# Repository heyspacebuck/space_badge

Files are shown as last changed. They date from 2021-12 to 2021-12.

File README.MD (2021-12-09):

# Space Buck's Space Badge

## Thoughts on designing a con badge with boopability

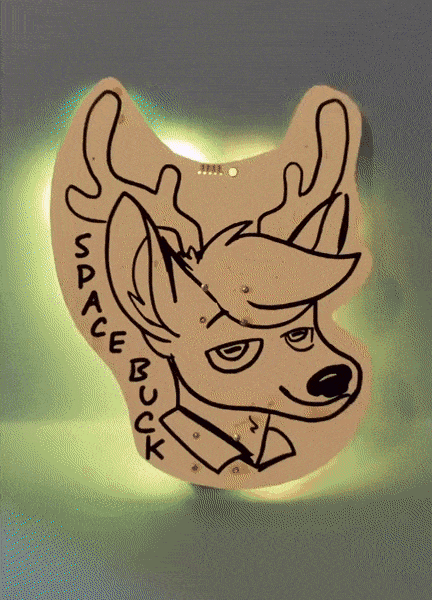
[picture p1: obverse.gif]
Animated gif of a deer face with animated backlighting


You probably don't need to be told that con badges are useful. Meeting someone in-person when you've only ever seen their avatar and username can be disorienting! This is especially true for real-life events in the furry fandom. A good fur con badge isn't just a nametag, it also shows off some facet of the wearer's personality. "Oh I know that panther, they're good at metalworking," "Oh I know that bear, she cards her own yarn," "Hey it's Space Buck, he makes goofy electronics!"

Naturally I thought it would be fun to make a PCB con badge for myself. The obverse face has, well, my face, and three large copper pours for capacitive touch purposes. The reverse has twelve WS2812B addressable LEDs, an ATtiny85, and a trio of dead-simple AT42QT1011 capacitive touch sensors. It's powered by a pair of 10440 li-ion cells and a 5V LDO, simply because I have a ton of those lying around. The ATtiny85 is programmed in-circuit with a SOICbite connector. In theory I could have just used the SOIC clip as intended, but for whatever reason I can never get them to make secure connections that way.

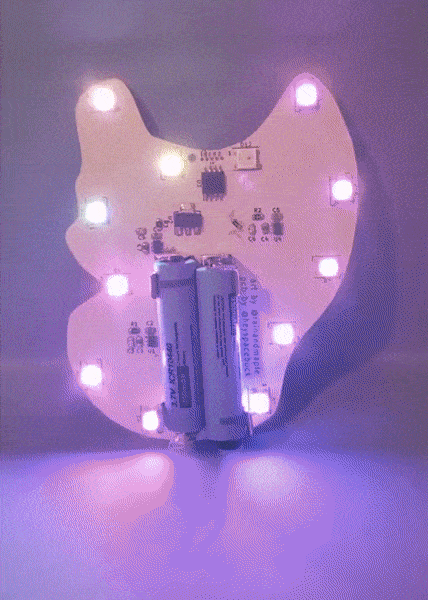
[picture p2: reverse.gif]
Animated gif of the reverse face of the PCB


How it works: The copper pours under the nose and the antlers are the only inputs and the RGB LEDs are the only outputs. Booping the snoot turns the system on or off. When on, one of six FastLED patterns plays across the LEDs. To switch to the next/previous patterns, just touch the right/left antlers.

The cute art is by [Fenn, @rainandmaple on Twitter](https://twitter.com/rainandmaple)! I got white soldermask because I intend to paint it someday. The git repo contains the circuit I used, but not Fenn's artwork. I don't recommend using the same circuit I used! Which brings us to future hardware improvements....

## Future hardware improvements

I'm happy with the badge for myself, but if I were making one for someone else, I'd put a lot more care into it. A physical power switch, for sure. A more normal Li-Po pouch battery, and a built-in USB charge circuit (sorry not sorry, I'm still using USB Micro B ports on all my designs). More LED patterns. I've designed a proof-of-concept circuit but haven't tried it for real yet.

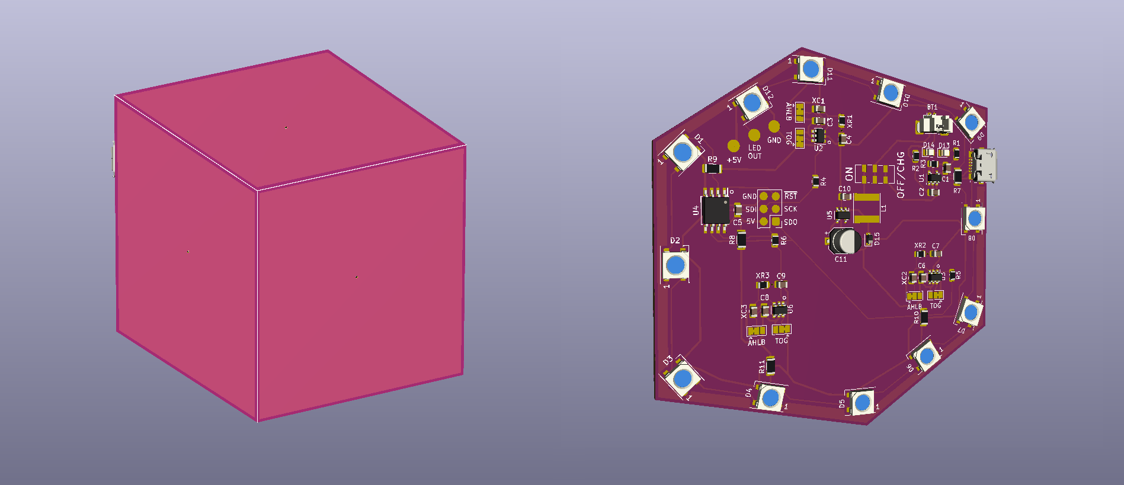
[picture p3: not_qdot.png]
KiCad render of an updated PCB badge circuit


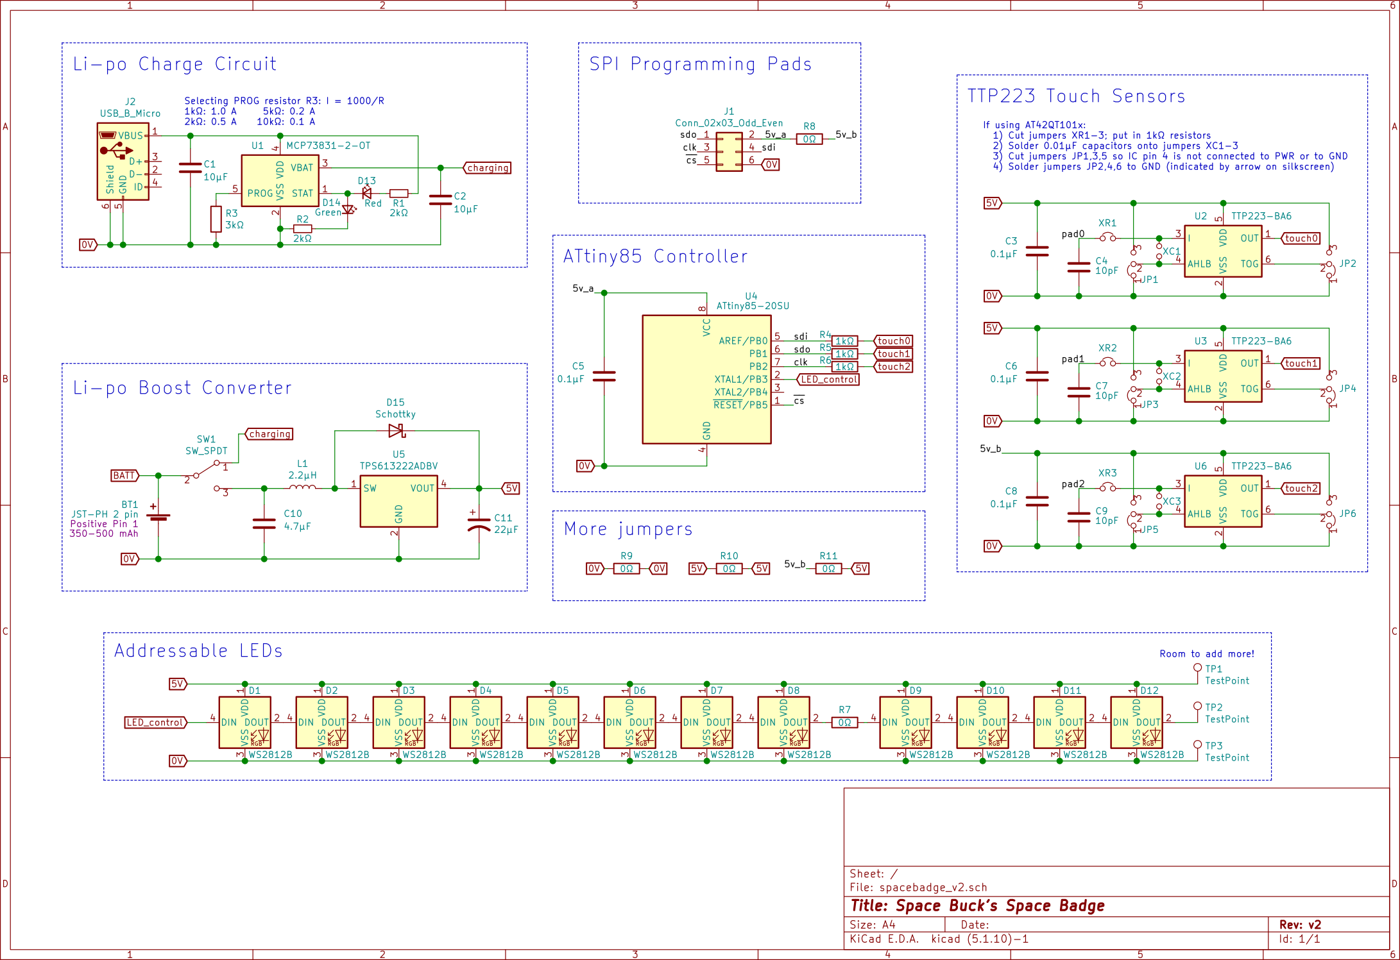
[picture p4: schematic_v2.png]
Schematic of an updated PCB badge circuit


### Power consumption

It should be easy to set up deep-sleep mode on the ATtiny85 and wait for an interrupt to turn the LEDs on. I suppose it's still possible to update this version to do that; I'd just have to update the code. In fact, I think I will do that!

...

Okay I'm back, the badge now enters deep-sleep mode when the lights are off and turns back on with a pin change interrupt. Now I know to attach this specific touch sensor to the INT0 pin (PB0, pin 5) for an easier time detecting rising-edge interrupts only.

### Power supply

The first badge's power system is bad: two 10440 li-ion cells in series, dropped to 5V with an LDO. I only did this because those were the parts I had on-hand. Were I building this for someone else, I'd use a regular pouch li-po cell, something in the 350-500 mAh range, and a boost converter like the TPS613222A to get the 5 volts expected by the WS2812b LEDs. And, of course, a built-in recharging circuit. I'd also add a physical power switch. We don't want the cap-touch sensors turning the badge on at inopportune times.

### Programming

Goodbye, SOICbite. The next version of the badge will have *no* visible copper on the obverse face. The SOICbite is lovely but as long as I'm using a SOIC-8 microcontroller I should just use the SOIC clip as intended. That said, I have trouble with keeping my SOIC clip to secured on the IC, and I like offering large pads for soldering wires to, so I've also stuck on some SMD pads that can be soldered to or probed with pogo pins.

The light show patterns are demos from the FastLED Arduino library. When compiled the current sketch uses about 70% of the ATtiny85's 8k flash, and about 40% of the RAM, so there's plenty of room for new features.

### Part flexibility

Ah, the chip shortage. Judging by the AT42QT101x lead times, I won't be using that IC in any designs for a while. The TTP223, which is a similar and much cheaper chip, is still available from many places, so I can adjust my designs to use that without much fuss. Alternately, I'd like to try turning some ATtiny10's into cap-touch sensors! The datasheet promises that Atmel's QTouch capacitive touch library is supported, but the actual documentation and libraries are nearly impossible to find on their website. Someone from Microchip guided me through the maze of broken links to get to some inscrutable libraries and an ATtiny10-specific tool that I'd describe as "so Visual Basic it hurts". It will take some time (and I'll have to find my HV programmer) but that's something to look forward to.

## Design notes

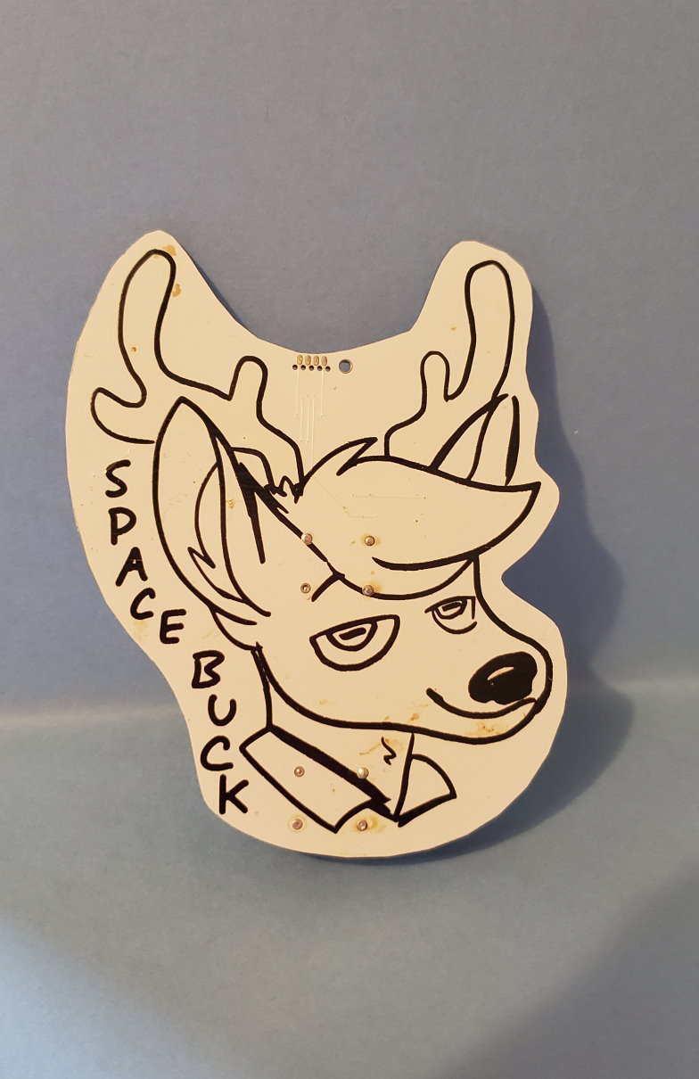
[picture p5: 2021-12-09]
obverse.jpg

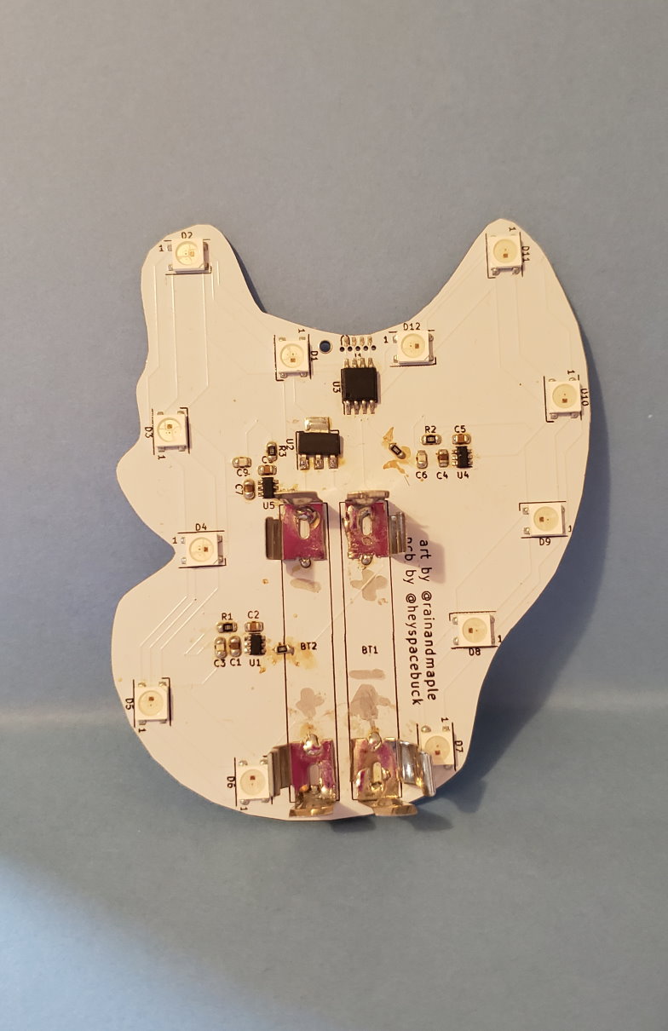
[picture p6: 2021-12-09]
reverse.jpg

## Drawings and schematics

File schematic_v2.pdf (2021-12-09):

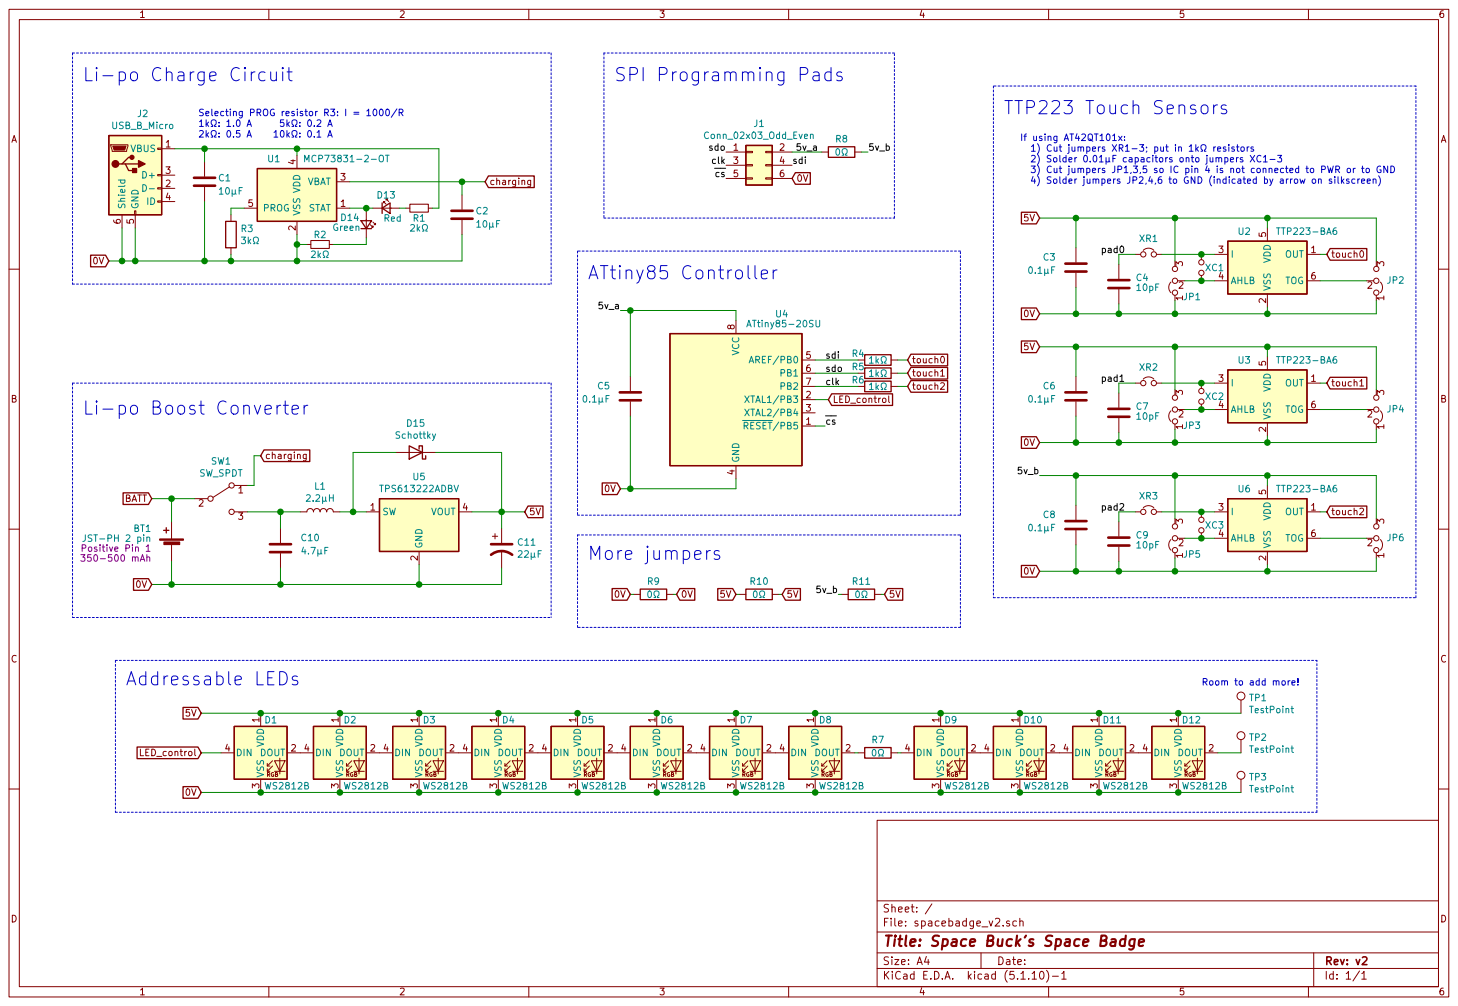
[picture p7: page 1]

Li-po Charge Circuit

If using AT42QT101x:
1) Cut jumpers XR1-3; put in 1k resistors
2) Solder 0.01F capacitors onto jumpers XC1-3
3) Cut jumpers JP1,3,5 so IC pin 4 is not connected to PWR or to GND
4) Solder jumpers JP2,4,6 to GND (indicated by arrow on silkscreen)

5 TOG 6 U2 TTP223-BA6 D13Red TP1 TestPoint TP2 TestPoint D15 Schottky C11

Li-po Boost Converter

JST-PH 2 pin Positive Pin 1
350-500 mAh

Id: 1/1 Title: Space Buck's Space Badge

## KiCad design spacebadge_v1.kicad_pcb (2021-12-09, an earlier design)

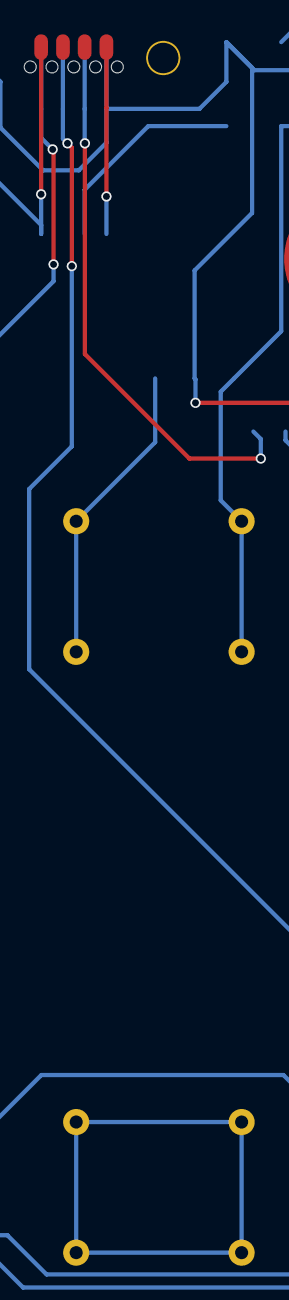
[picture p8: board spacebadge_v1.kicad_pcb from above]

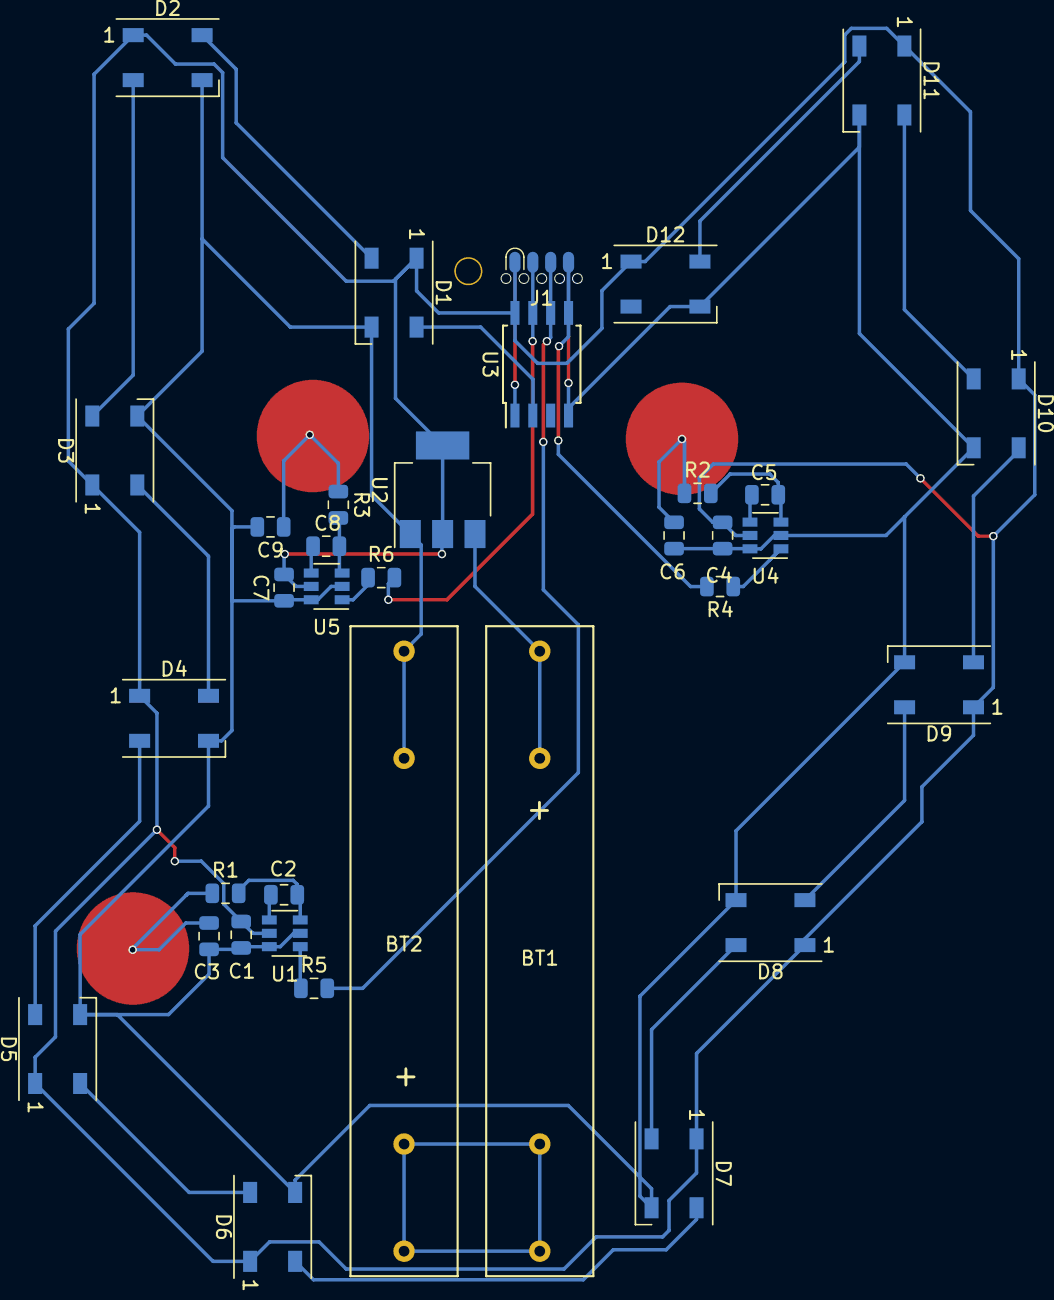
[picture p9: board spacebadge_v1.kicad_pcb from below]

Board: 2 copper layers, 35 parts (35 on the bottom side), 32 nets.

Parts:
BT1, BT2: Battery_Cell; bk-82-10440
C1, C4, C7: .1 μF; C_0805_2012Metric
C2, C5, C8: .01 μF; C_0805_2012Metric
C3, C6, C9: 5-20 pF; C_0805_2012Metric
D1, D2, D3, D4, D5, D6, D7, D8, D9, D10, D11, D12: WS2812B; LED_WS2812B_PLCC4_5.0x5.0mm_P3.2mm
J1: Conn_02x04_Counter_Clockwise; SOIC_clipProgSmall
R1, R2, R3, R4, R5, R6: 1 kΩ; R_0805_2012Metric
U1, U4, U5: AT42QT1011-TSHR; SOT-23-6
U2: AP1117-50; SOT-223-3_TabPin2
U3: ATtiny85-20SU; SOIJ-8_5.3x5.3mm_P1.27mm

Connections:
0V: BT2.2, C1.1, C3.2, C4.1, C6.2, C7.1, C9.2, D1.3, D2.3, D3.3, D4.3, D5.3, D6.3, D7.3, D8.3, D9.3, D10.3, D11.3, D12.3, J1.5, U1.2, U1.6, U2.1, U3.4, U4.2, U4.6, U5.2, U5.6
5V: C1.2, C4.2, C7.2, D1.1, D2.1, D3.1, D4.1, D5.1, D6.1, D7.1, D8.1, D9.1, D10.1, D11.1, D12.1, J1.1, U1.5, U2.2, U3.8, U4.5, U5.5
/clk: J1.2, R6.2, U3.7
/sdi: J1.4, R4.2, U3.5
/sdo: J1.3, R5.2, U3.6
/~cs: J1.8, U3.1
unnamed: BT1.1, U2.3
unnamed: BT1.2, BT2.1
unnamed: C2.1, R1.2, U1.3
unnamed: C2.2, U1.4
unnamed: C5.1, R2.2, U4.3
unnamed: C5.2, U4.4
unnamed: C8.1, R3.2, U5.3
unnamed: C8.2, U5.4
unnamed: D1.2, D2.4
unnamed: D2.2, D3.4
unnamed: D3.2, D4.4
unnamed: D4.2, D5.4
unnamed: D5.2, D6.4
unnamed: D6.2, D7.4
unnamed: D7.2, D8.4
unnamed: D8.2, D9.4
unnamed: D10.2, D11.4
unnamed: D9.2, D10.4
unnamed: D11.2, D12.4
l_antler: C6.1, R2.1
led: D1.4, U3.2
r_antler: C9.1, R3.1
snout: C3.1, R1.1
touch0: R5.1, U1.1
touch1: R4.1, U4.1
touch2: R6.1, U5.1

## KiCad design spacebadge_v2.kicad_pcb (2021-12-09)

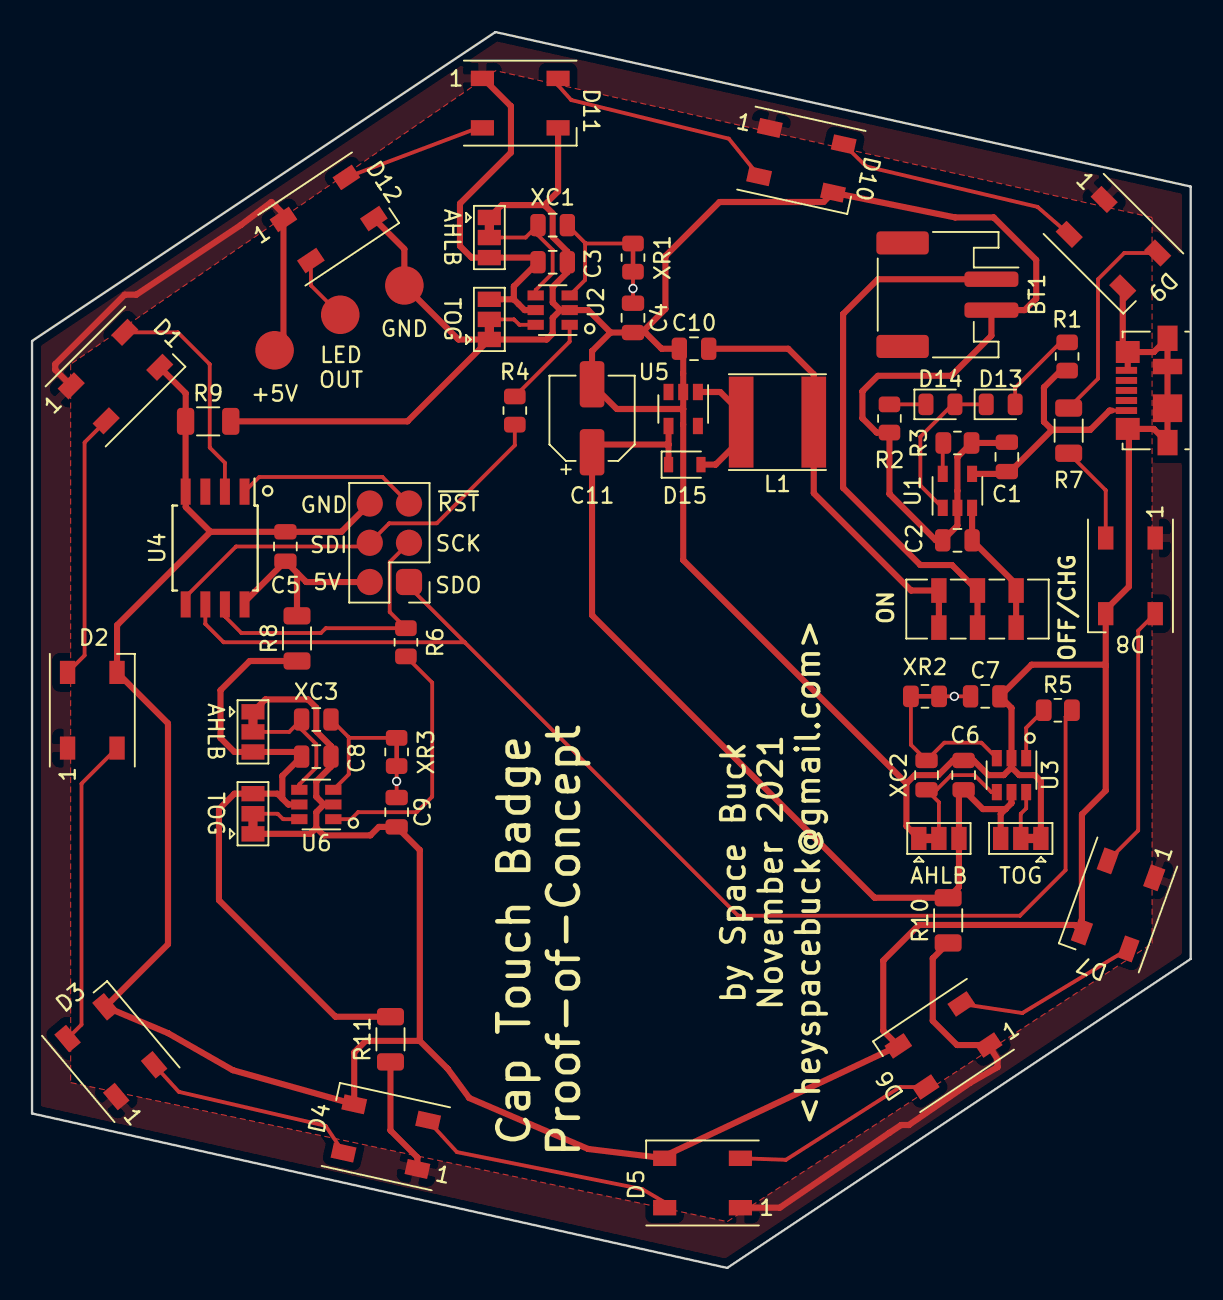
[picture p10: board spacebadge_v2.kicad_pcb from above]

Board: 2 copper layers, 75.0 x 80.0 mm, 63 parts (0 on the bottom side), 46 nets.

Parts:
BT1: JST-PH 2 pin; JST_PH_S2B-PH-SM4-TB_1x02-1MP_P2.00mm_Horizontal
C1, C2: 10μF; C_0805_2012Metric
C3, C5, C6, C8: 0.1μF; C_0805_2012Metric
C4, C7, C9: 10pF; C_0805_2012Metric
C10: 4.7μF; C_0805_2012Metric
C11: 22μF; CP_Elec_5x5.4
D1, D2, D3, D4, D5, D6, D7, D8, D9, D10, D11, D12: WS2812B; LED_WS2812B_PLCC4_5.0x5.0mm_P3.2mm
D13: Red; LED_0805_2012Metric
D14: Green; LED_0805_2012Metric
D15: Schottky; D_SOD-323
J1: Conn_02x03_Odd_Even; SMDPads_2x03_P2.54mm
J2: USB_B_Micro; USB_Micro-B_Molex_47346-0001
JP1, JP2, JP3, JP4, JP5, JP6: Jumper_3_Bridged12_Small; SolderJumper-3_P1.3mm_Bridged12_Pad1.0x1.5mm
L1: 2.2μH; L_Taiyo-Yuden_NR-60xx
R1, R2: 2kΩ; R_0805_2012Metric
R3: R; R_0805_2012Metric
R4, R5, R6: 1kΩ; R_0805_2012Metric
R7, R8, R9, R10, R11: 0Ω; R_1206_3216Metric
SW1: SW_SPDT; SW_DPDT_CK_JS202011JCQN
TP1, TP2, TP3: TestPoint; TestPoint_Pad_D2.5mm
U1: MCP73831-2-OT; SOT-23-5
U2, U3, U6: TTP223-BA6; SOT-23-6
U4: ATtiny85-20SU; SOIJ-8_5.3x5.3mm_P1.27mm
U5: TPS613222ADBV; SOT-23-5
XC1, XC2, XC3: Jumper_NO_Small; C_0805_2012Metric
XR1, XR2, XR3: Jumper_NC_Small; 0805_NC

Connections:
0V: BT1.2, C1.1, C2.1, C3.1, C4.2, C5.1, C6.1, C7.2, C8.1, C9.2, C10.1, C11.2, D1.3, D2.3, D3.3, D4.3, D5.3, D6.3, D7.3, D8.3, D9.3, D10.3, D11.3, D12.3, J1.6, J2.5, J2.6, JP1.1, JP2.1, JP3.1, JP4.1, JP5.1, JP6.1, R2.1, R3.2, R9.1, R9.2, TP3.1, U1.2, U2.2, U3.2, U4.4, U5.2, U6.2
5V: C3.2, C6.2, C11.1, D1.1, D2.1, D3.1, D4.1, D5.1, D6.1, D7.1, D8.1, D9.1, D10.1, D11.1, D12.1, D15.1, JP1.3, JP2.3, JP3.3, JP4.3, R10.1, R10.2, R11.1, TP1.1, U2.5, U3.5, U5.4
/5v_a: C5.2, J1.2, R8.2, U4.8
/5v_c: C8.2, JP5.3, JP6.3, R8.1, R11.2, U6.5
/clk: J1.3, R6.2, U4.7
/pad0: C4.1, XR1.1
/pad1: C7.1, XR2.1
/pad2: C9.1, XR3.1
/sdi: J1.4, R4.2, U4.5
/sdo: J1.1, R5.2, U4.6
/~cs: J1.5, U4.1
BATT: BT1.1, SW1.2
LED_control: D1.4, U4.2
unnamed: C1.2, J2.1, R1.1, U1.4
unnamed: C10.2, L1.1, SW1.3
unnamed: D1.2, D2.4
unnamed: D2.2, D3.4
unnamed: D3.2, D4.4
unnamed: D4.2, D5.4
unnamed: D5.2, D6.4
unnamed: D6.2, D7.4
unnamed: D7.2, D8.4
unnamed: D8.2, R7.2
unnamed: D9.4, R7.1
unnamed: D10.2, D11.4
unnamed: D9.2, D10.4
unnamed: D11.2, D12.4
unnamed: D12.2, TP2.1
unnamed: D13.1, D14.2, U1.1
unnamed: D13.2, R1.2
unnamed: D14.1, R2.2
unnamed: D15.2, L1.2, U5.1
unnamed: JP1.2, U2.4, XC1.2
unnamed: JP2.2, U2.6
unnamed: JP3.2, U3.4, XC2.2
unnamed: JP4.2, U3.6
unnamed: JP5.2, U6.4, XC3.2
unnamed: JP6.2, U6.6
unnamed: R3.1, U1.5
unnamed: U2.3, XC1.1, XR1.2
unnamed: U3.3, XC2.1, XR2.2
unnamed: U6.3, XC3.1, XR3.2
charging: C2.2, SW1.1, U1.3
touch0: R4.1, U2.1
touch1: R5.1, U3.1
touch2: R6.1, U6.1

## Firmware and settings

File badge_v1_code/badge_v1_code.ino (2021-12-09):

#include <FastLED.h>

FASTLED_USING_NAMESPACE

// Derived from FastLED "100-lines-of-code" demo reel
// Adds inputs from three capacitive touch sensors and stuff

#if defined(FASTLED_VERSION) && (FASTLED_VERSION < 3001000)
#warning "Requires FastLED 3.1 or later; check github for latest code."
#endif

#define DATA_PIN    3
#define LED_TYPE    WS2812
#define COLOR_ORDER GRB
#define NUM_LEDS    12
CRGB leds[NUM_LEDS];

#define ARRAY_SIZE(A) (sizeof(A) / sizeof((A)[0]))

#define BRIGHTNESS          96
#define FRAMES_PER_SECOND   60
#define DELAY_FRAMES        10  // Wait this many frames before checking for another touch event

#define snoot 1      // PB1 (pin 6 on SOIC-8 package)
#define l_antler 0   // PB0 (pin 5)
#define r_antler 2   // PB2 (pin 7)

uint8_t gCurrentPatternNumber = 0; // Index number of which pattern is current
uint8_t gHue = 0; // rotating "base color" used by many of the patterns

volatile bool snoot_pressed = false;     // If TRUE, PB1 just went from LOW to HIGH
volatile bool l_antler_pressed = false;  // If TRUE, PB0 just went from LOW to HIGH
volatile bool r_antler_pressed = false;  // If TRUE, PB2 just went from LOW to HIGH

volatile uint8_t pattern = 0;          // Indicates which pattern is currently active (0-5 at the moment)
volatile uint8_t touch_cooldown = 0;   // How many frames to wait before checking for another touch event

// FastLED light show patterns defined in another file
#include "lightshows.hpp"

// Sleep functions defined in another file
#include "sleep.hpp"

// Interrupt behavior defined in another file
#include "interrupts.hpp"

void setup() {
  delay(200); // Delay before setup, not sure why I put this in but okay
  
  // tell FastLED about the LED strip configuration
  FastLED.addLeds<LED_TYPE,DATA_PIN,COLOR_ORDER>(leds, NUM_LEDS).setCorrection(TypicalLEDStrip);

  // set master brightness control
  FastLED.setBrightness(BRIGHTNESS);

  // Configure other pins
  pinMode(l_antler, INPUT);     // PB0
  pinMode(r_antler, INPUT);     // PB2
  pinMode(snoot, INPUT);        // PB1--snoot SHOULD be on PB0/INT0 for interrupt purposes but I didn't know that at the time

  PCMSK = 1 << PCINT1;          // Pin Change Interrupt triggered only by PB1 when listening for interrupts (don't enable interrupts yet) (Datasheet p.51-52)
  MCUCR |= 2 << SM0;            // Set sleep mode to Deep Sleep (Datasheet p.37)
  
  // End setup by clearing display and putting board into sleep mode
  // (note: enable interrupts when entering sleep mode, disable when leaving)
  allBlack();
  enterDeepSleep();
}

// When awake and looping:
// Every frame (60 frames per second), check for capacitive touch inputs and update light show
// If snoot is booped, turn off light show and enter sleep mode (but first, enable pin change interrupt so we can exit sleep mode at some point)
// If antler is booped, change patterns
void loop() {
  // Call the current pattern function once, updating the 'leds' array
  gPatterns[gCurrentPatternNumber]();

  // send the 'leds' array out to the actual LED strip
  FastLED.show();  

  // insert a delay to keep the framerate modest
  FastLED.delay(1000/FRAMES_PER_SECOND);

  // do some periodic updates
  EVERY_N_MILLISECONDS( 20 ) { gHue++; } // slowly cycle the "base color" through the rainbow

  // If we are in the touch-cooldown period, decrement the period by one frame
  // If we are NOT in the touch-cooldown period, check for touch events
  if (touch_cooldown > 0) {
    touch_cooldown--;
  } else {
    snoot_pressed = digitalRead(snoot);
    l_antler_pressed = digitalRead(l_antler);
    r_antler_pressed = digitalRead(r_antler);

    // If the snoot_booped has gone from LOW to HIGH, shut down light show and enter deep sleep
    if (snoot_pressed) {
      snoot_pressed = false;
      allBlack();
      enterDeepSleep();
    }

    // If l_antler goes from LOW to HIGH, go to previous light show and set touch_cooldown to 5 frames
    else if (l_antler_pressed) {
      prevPattern();
      touch_cooldown = 5;
      l_antler_pressed = false;
    }

    else if (r_antler_pressed) {
      nextPattern();
      touch_cooldown = 5;
      r_antler_pressed = false;
    }
  }
}

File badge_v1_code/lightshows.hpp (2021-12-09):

#ifndef LIGHTSHOWS_HPP
#define LIGHTSHOWS_HPP

#include <FastLED.h>

void rainbow() {
  // FastLED's built-in rainbow generator
  fill_rainbow( leds, NUM_LEDS, gHue, 7);
}

void addGlitter( fract8 chanceOfGlitter) {
  if( random8() < chanceOfGlitter) {
    leds[ random16(NUM_LEDS) ] += CRGB::White;
  }
}

void rainbowWithGlitter() {
  // built-in FastLED rainbow, plus some random sparkly glitter
  rainbow();
  addGlitter(80);
}

void confetti() {
  // random colored speckles that blink in and fade smoothly
  fadeToBlackBy( leds, NUM_LEDS, 10);
  int pos = random16(NUM_LEDS);
  leds[pos] += CHSV( gHue + random8(64), 200, 255);
}

void sinelon() {
  // a colored dot sweeping back and forth, with fading trails
  fadeToBlackBy( leds, NUM_LEDS, 20);
  int pos = beatsin16( 13, 0, NUM_LEDS-1 );
  leds[pos] += CHSV( gHue, 255, 192);
}

void bpm() {
  // colored stripes pulsing at a defined Beats-Per-Minute (BPM)
  uint8_t BeatsPerMinute = 62;
  CRGBPalette16 palette = PartyColors_p;
  uint8_t beat = beatsin8( BeatsPerMinute, 64, 255);
  for( int i = 0; i < NUM_LEDS; i++) { //9948
    leds[i] = ColorFromPalette(palette, gHue+(i*2), beat-gHue+(i*10));
  }
}

void juggle() {
  // eight colored dots, weaving in and out of sync with each other
  fadeToBlackBy( leds, NUM_LEDS, 20);
  byte dothue = 0;
  for( int i = 0; i < 8; i++) {
    leds[beatsin16( i+7, 0, NUM_LEDS-1 )] |= CHSV(dothue, 200, 255);
    dothue += 32;
  }
}

// List of patterns to cycle through.  Each is defined as a separate function below.
typedef void (*SimplePatternList[])();
SimplePatternList gPatterns = { rainbow, rainbowWithGlitter, confetti, sinelon, juggle, bpm };


void nextPattern() {
  // add one to the current pattern number, and wrap around at the end
  gCurrentPatternNumber = (gCurrentPatternNumber + 1) % ARRAY_SIZE( gPatterns);
}

void prevPattern() {
  gCurrentPatternNumber = (gCurrentPatternNumber + ARRAY_SIZE( gPatterns) - 1) % ARRAY_SIZE( gPatterns);
}

// Shut off LEDs
void allBlack() {
  for (int i=0; i<NUM_LEDS; i++) {
    leds[i] = CRGB::Black;
  }
  FastLED.show();
}

void red(int n) {
  leds[n] = CRGB::Red;
  FastLED.show();
}

void blue(int n) {
  leds[n] = CRGB::Blue;
  FastLED.show();
}

void green(int n) {
  leds[n] = CRGB::Green;
  FastLED.show();
}

#endif

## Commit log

2021-12-09 Initial public commit
    [spacebadge_v1.kicad_pcb, spacebadge_v1.sch, spacebadge_v2.kicad_pcb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]
2021-12-09 Add schematic v2
    [spacebadge_v2.sch]
